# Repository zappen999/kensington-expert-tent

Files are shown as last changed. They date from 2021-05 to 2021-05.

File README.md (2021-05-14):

# Tenting spacer for Kensington Expert Trackball

Parametric tenting spacer to adjust the roll and pitch of the Kensington
Expert Trackball.

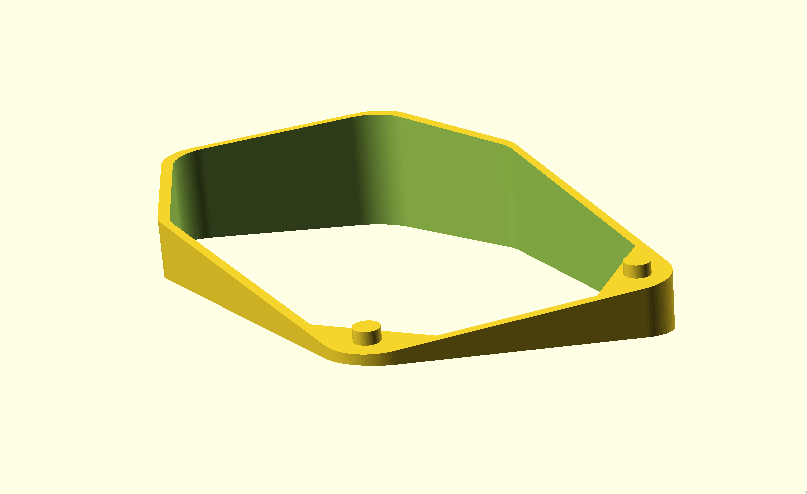
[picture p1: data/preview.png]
Preview

*Preview of 8° roll, -8° pitch with wrist rest support enabled.*

## Customization

The model is built with OpenSCAD which is a software for creating
parametric, solid 3D CAD objects using programming. Configure the model
parameters as you please, then export the desired model into a STL file
for 3D printing.

The following parameters can be changed using the customizer in
OpenSCAD:

- **Wrist rest** - Whether or not to include support for wrist rest.
- **Roll angle** - Side-to-side angle of the spacer.
- **Pitch angle** - Back/forth angle of the spacer.
- **Base height** - Height of lowest point from the surface.
- **Wall thickness** - Useful for 3D printing.

## 3D printing

STL file of default model is available in the [stl/](./stl) directory. I
don't recommend using it. You should customize the model to fit *you*.

- Material: PLA
- 40% infill (may work with less)
- No supports

Printing time approx 6h 15m with 50mm/s speed, 200mm/s travel.

## Images

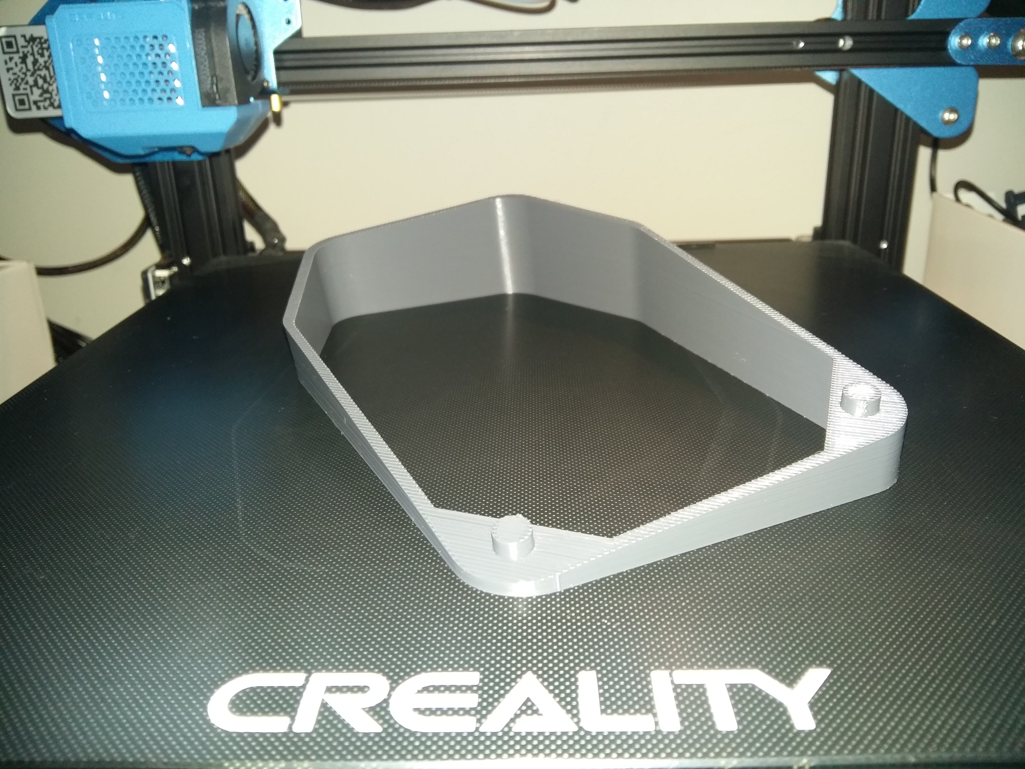
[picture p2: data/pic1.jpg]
Front view

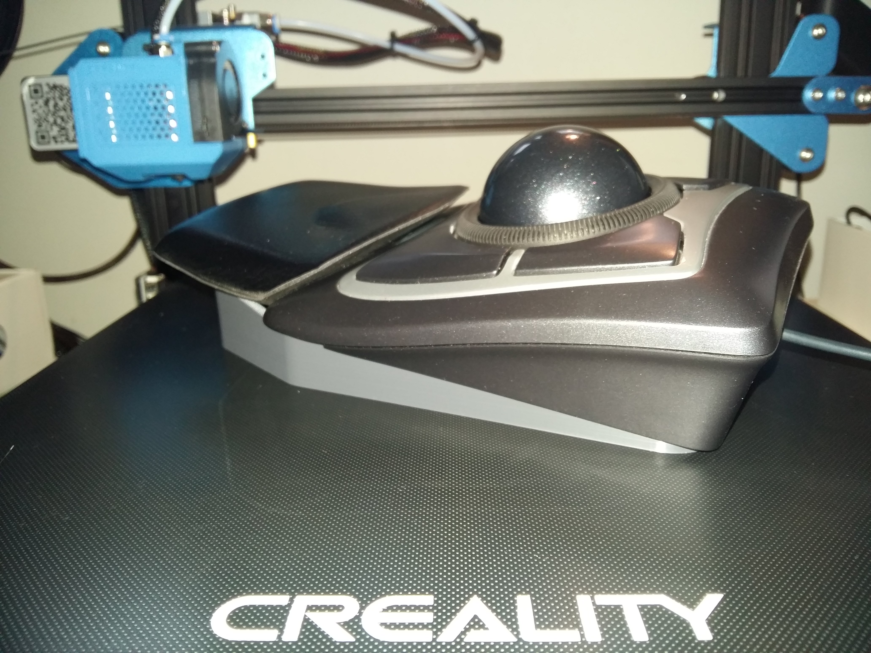
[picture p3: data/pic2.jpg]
Side view

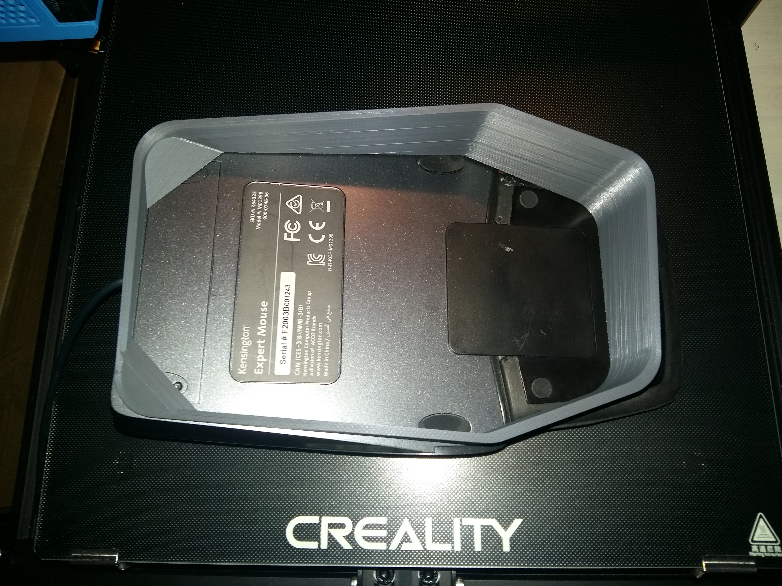
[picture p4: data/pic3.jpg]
Bottom view

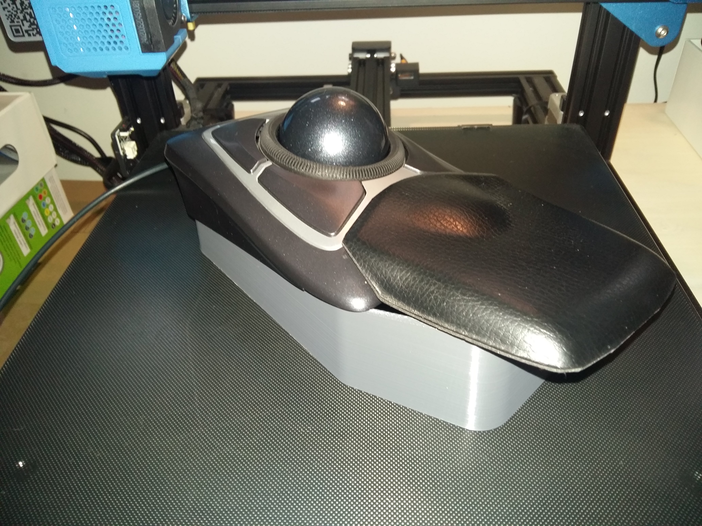
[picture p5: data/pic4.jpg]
Back view

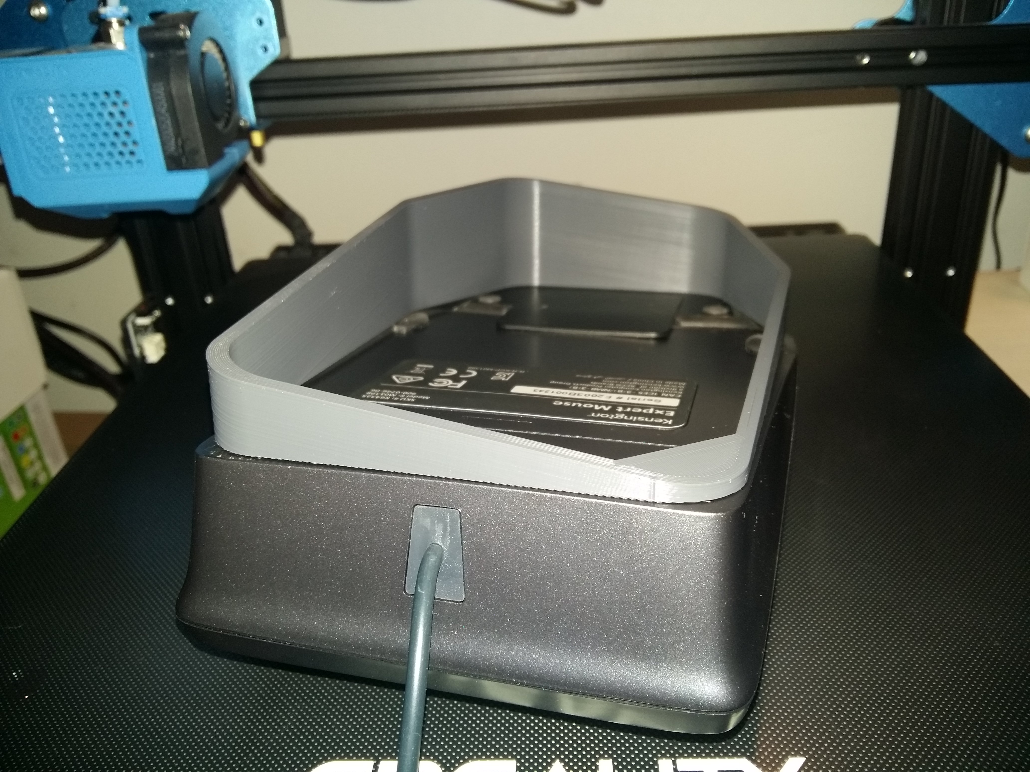
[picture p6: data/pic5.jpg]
Bottom front view


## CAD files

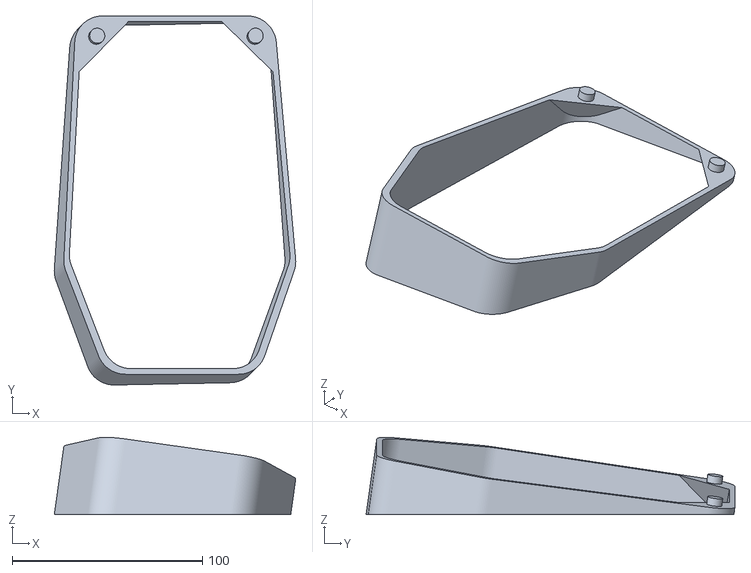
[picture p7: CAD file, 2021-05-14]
stl/v1_8roll_-8pitch_3wall.stl
126.8 x 193.8 x 40.6

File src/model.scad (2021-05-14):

// Whether or not to include support for wrist rest
wrist_rest=true;

// The side-to-side angle of the spacer
roll_angle=8; // [-40:40]

// The back/forth angle of the spacer
pitch_angle=-8; // [-30:0]

// Height of lowest point from the surface
base_height=2; // [0:20]

// Wall thickness
wall_thickness=3; // [0.5:10]

// ------------------------------------
/* [Constants (don't touch these)] */
front_w=107;
front_hole_cc=84;
back_w=123;
base_len=145;
platform_h=200;
corner_radius=15;
pin_diameter=8;

wrist_rest_front_w=110;
wrist_rest_back_w=90;
wrist_rest_len=90;

$fn = 100;

module rotate_about_pt(x, y, z, pt) {
	translate(pt)
		rotate([x, y, z])
			translate(-pt)
				children();
}

module shape(front_width, back_width, length, height, corner_rad, shrink_offset=0) {
	minkowski() {
		offs=corner_rad+shrink_offset;
		front_left=[-(front_width/2)+offs, (length/2)-offs];
		front_right=[(front_width/2)-offs, (length/2)-offs];
		back_right=[(back_width/2)-offs, -(length/2)+offs];
		back_left=[-(back_width/2)+offs, -(length/2)+offs];

		back_right_rest=[(wrist_rest_back_w/2)-offs, -(length/2)-(wrist_rest_len/2)+offs];
		back_left_rest=[-(wrist_rest_back_w/2)+offs, -(length/2)-(wrist_rest_len/2)+offs];

		linear_extrude(height, center=true)
			polygon(wrist_rest ? [
				front_left,
				front_right,
				back_right,
				back_right_rest,
				back_left_rest,
				back_left,
			] : [
				front_left,
				front_right,
				back_right,
				back_left,
			]);
		cylinder(height, r=corner_rad, center=true);
	}
}

module hollow_shape() {
	difference() {
		shape(front_w, back_w, base_len, platform_h, corner_radius);
		translate([0, 0, -0.1])
			shape(
				front_w,
				back_w,
				base_len,
				platform_h+10,
				corner_radius,
				wall_thickness
			);
	}
}

module cut_box() {
	cut_box_w=1000;
	cut_box_l=1000;
	cut_box_h=1000;

	translate([0, 0, -500])
		cube([cut_box_w, cut_box_l, cut_box_h], center=true);
}

module on_top_plane() {
	x_origin=roll_angle < 0 ? -front_w/2 : front_w/2;
	y_origin=base_len/2;

	rotate_about_pt(pitch_angle, roll_angle, 0, [x_origin, y_origin])
		translate([0, 0, -platform_h+base_height])
			children();
}

module model() {
	on_top_plane()
		hollow_shape();
}

module solid_model() {
	on_top_plane()
		shape(front_w, back_w, base_len, platform_h, corner_radius);
}

module cut_pins() {
	intersection() {
		translate([0, 0, 50+platform_h])
			cube([1000, 1000, 100], center=true);

		children();
	}
}

module mount_pins() {
	// left
	cut_pins()
		translate([-front_hole_cc/2, base_len/2-corner_radius+4, 0])
			cylinder(platform_h+4, d=pin_diameter);

	// right
	cut_pins()
		translate([front_hole_cc/2, base_len/2-corner_radius+4, 0])
			cylinder(platform_h+4, d=pin_diameter);
}

module corner_box(left=true) {
	intersection() {
		solid_model();

		on_top_plane()
			translate([left ? -front_hole_cc/2 : front_hole_cc/2, base_len/2, platform_h+53])
				rotate([40, 0, left ? 45 : -45])
					cube([90, 90, 1000], center=true);
	}
}

difference() {
	union() {
		model();
		on_top_plane()
			mount_pins();
		corner_box(true);
		corner_box(false);
	}
	cut_box();
}

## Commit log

2021-05-12 feat(model): Add initial draft of tenting part
    [model.scad]
2021-05-12 docs(readme): Add readme
    [model.scad]
2021-05-13 feat(model): Add support for wrist rest
    - Added support for roll angle greater and lesser than 0 for right/left
    handed.
    - Add descriptions for parameters.
    [model.scad]
2021-05-13 fix(model): Adjust geometry after test prints
    [model.scad]
2021-05-13 refactor(model): Make corner boxes smaller
    Saving some filament and print time.
    [model.scad]
2021-05-14 docs(readme): Add build pics, change default settings
    Changed default parameter values to match the images in README. Added
    STL file of the default settings.
    [model.scad, v1_8roll_-8pitch_3wall.stl]
